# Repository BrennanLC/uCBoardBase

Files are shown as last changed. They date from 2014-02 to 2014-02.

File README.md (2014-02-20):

uCBoardBase
===========

Microcontroller breakout board built with the Texas Instruments TM4C123BE6PM.

Design has not yet been verified. Build at your own risk!

Files:

uCBoardBase.pdf - Copy of board schematic in PDF format
uCBoardBase.sch - Board schematic eagle file 
uCBoardBase.brd - Board layout eagle file
uCBoardBaseBoard.pdf - Board layout in PDF format

schematic and board layout built with Eagle 6.4.0 Standard. More info and 
download available here:

https://www.cadsoftusa.com/

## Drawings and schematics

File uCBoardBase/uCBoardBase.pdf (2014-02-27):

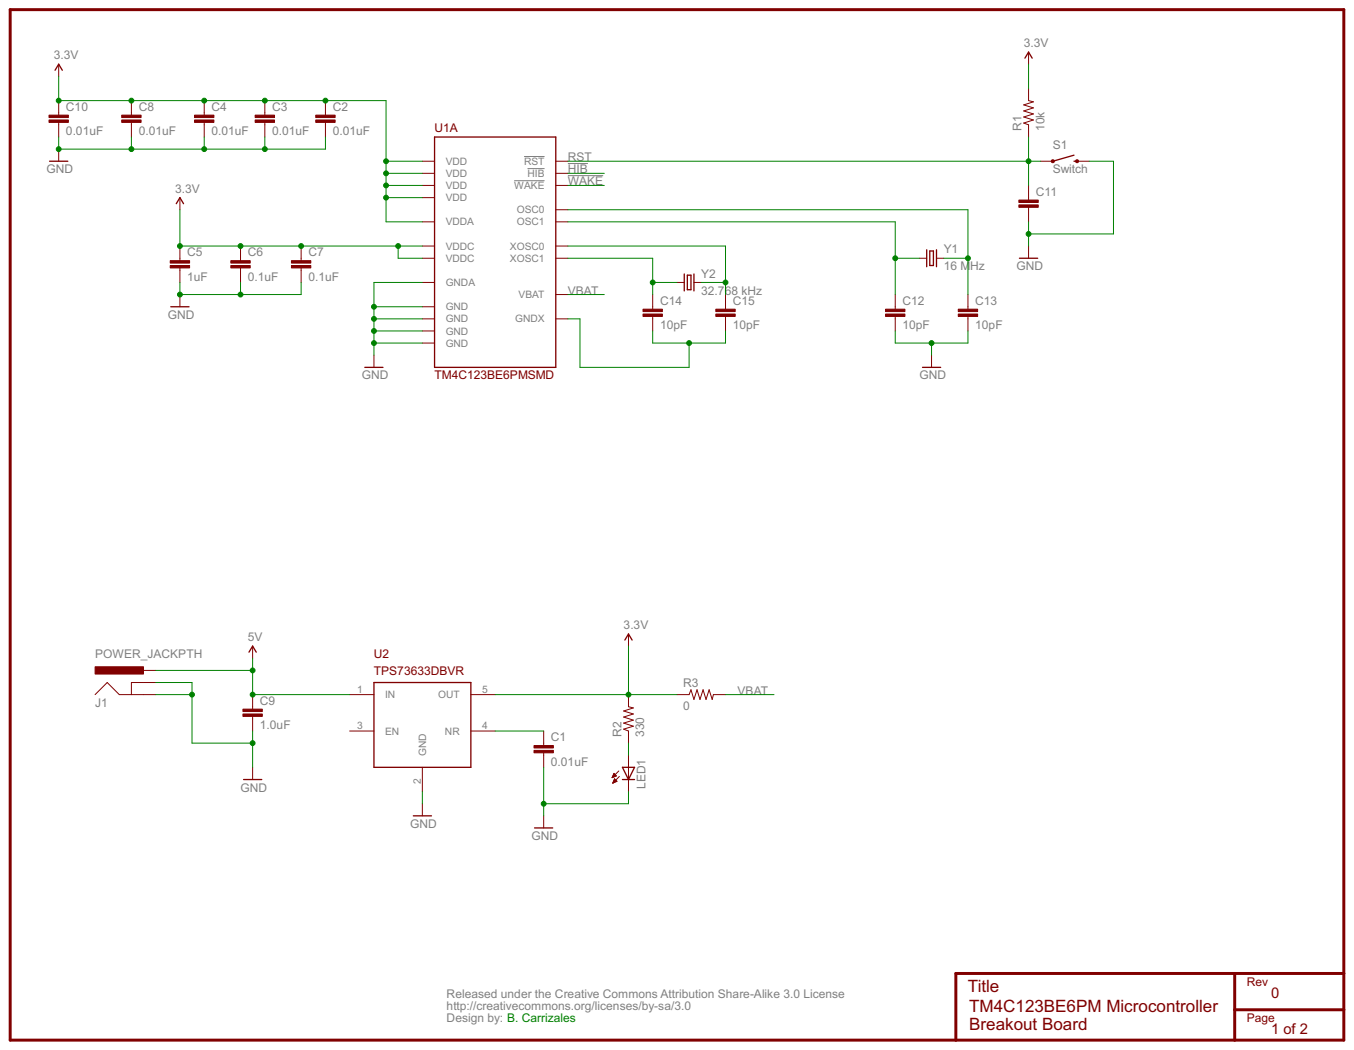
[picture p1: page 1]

VDDA
VDDC GNDA GND GND GND GND

Released under the Creative Commons Attribution Share-Alike 3.0 License
http://creativecommons.org/licenses/by-sa/3.0
Design by:

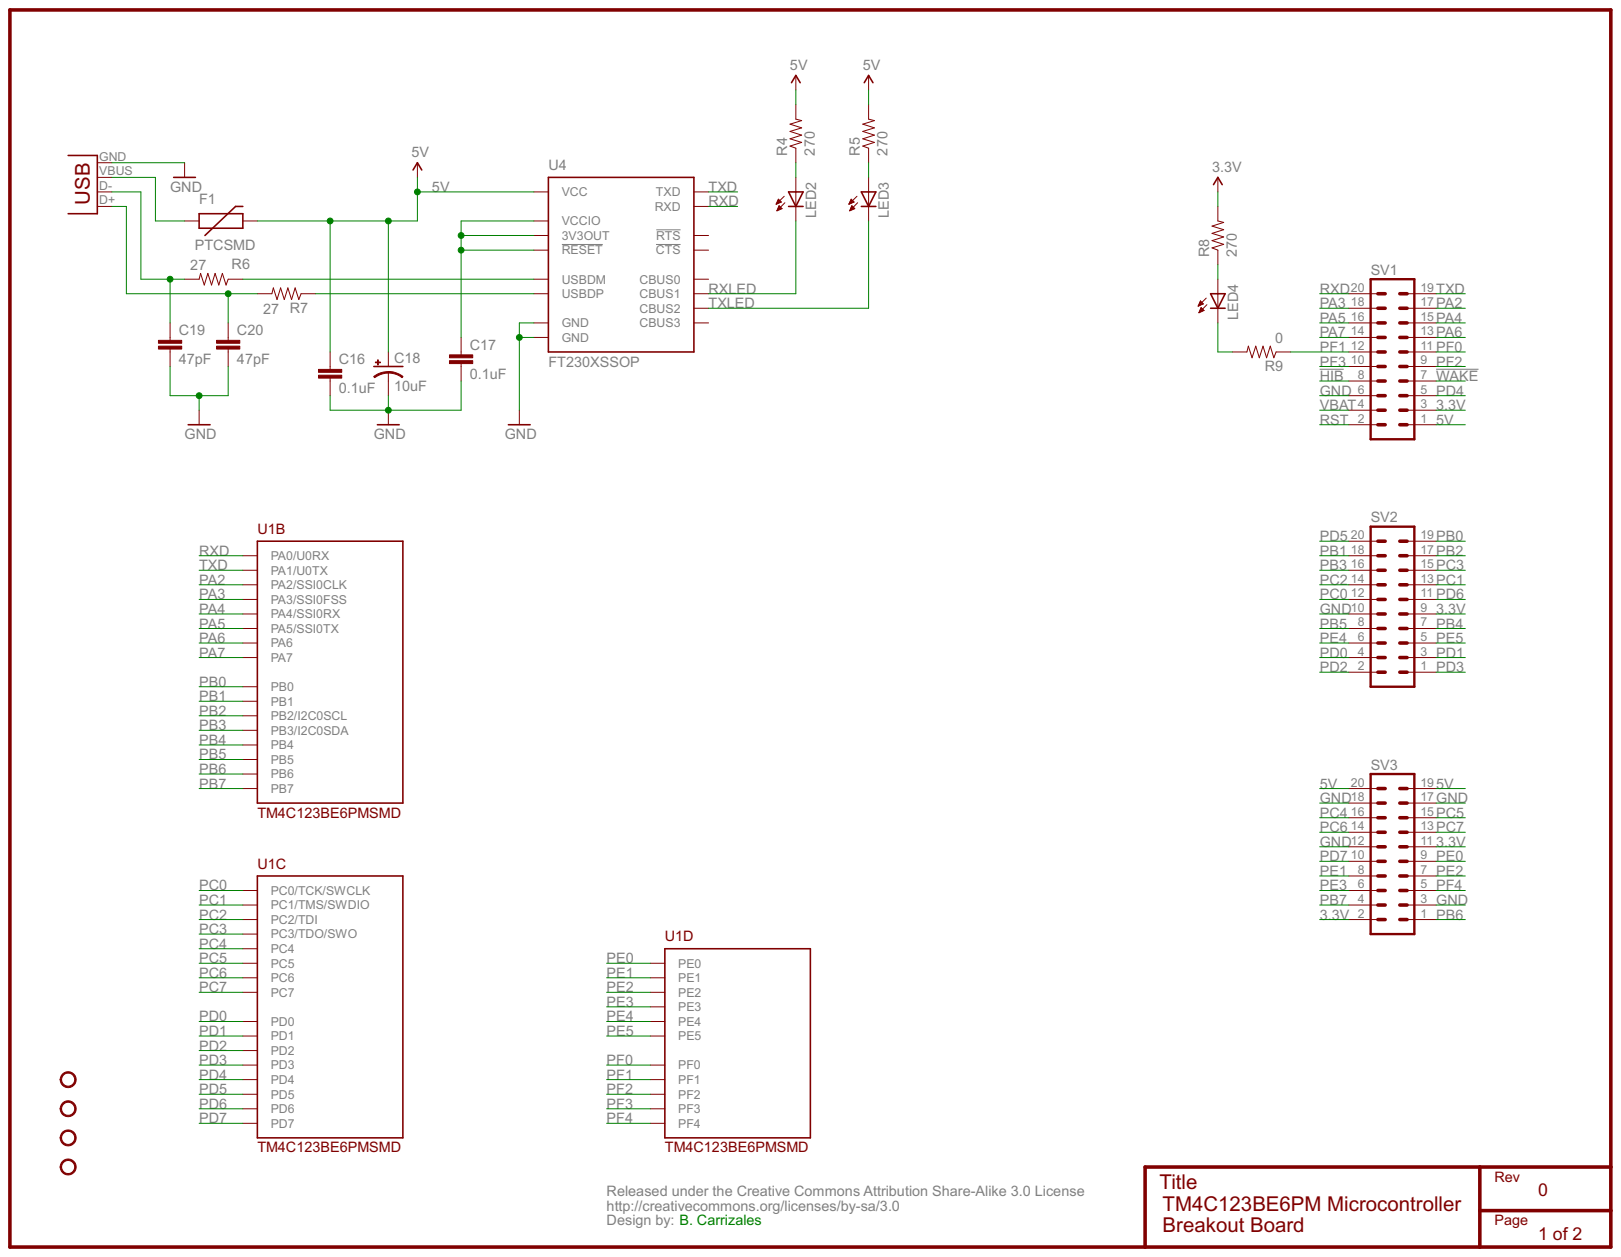
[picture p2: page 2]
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

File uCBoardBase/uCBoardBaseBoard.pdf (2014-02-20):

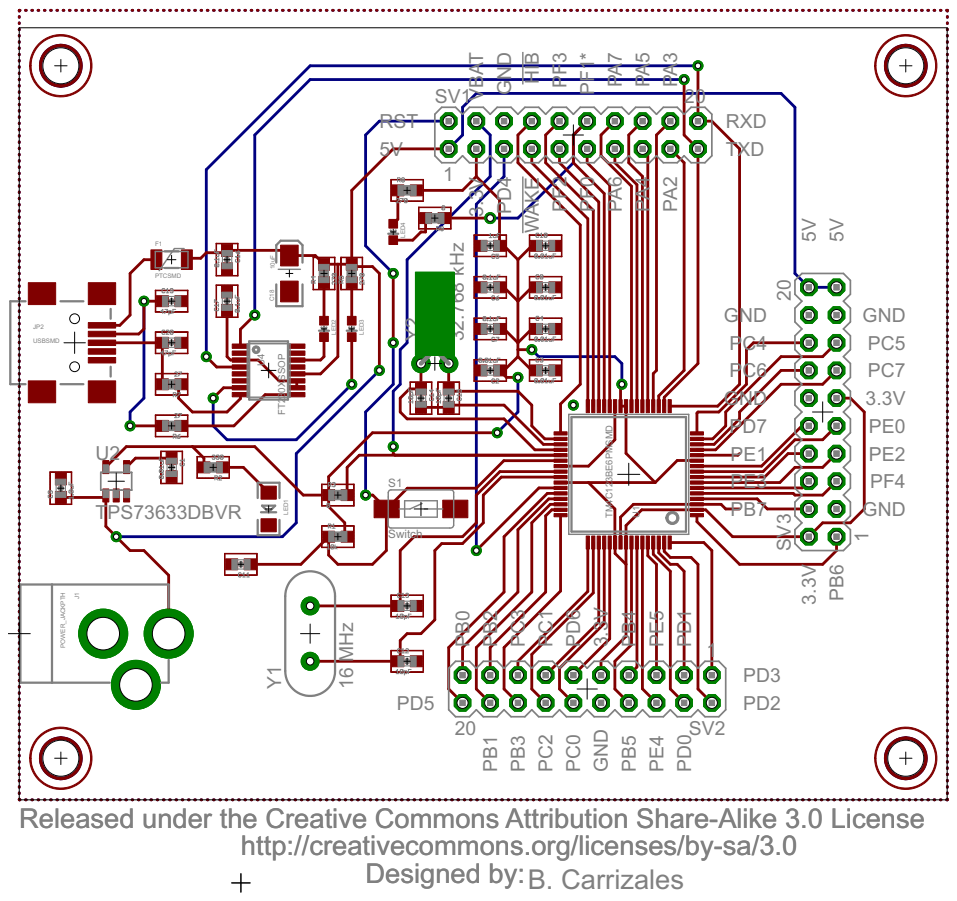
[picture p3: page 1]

POWER_JACKPTH Released under the Creative Commons Attribution Share-Alike 3.0 License

Released under the Creative Commons Attribution Share-Alike 3.0 License

http://creativecommons.org/licenses/by-sa/3.0

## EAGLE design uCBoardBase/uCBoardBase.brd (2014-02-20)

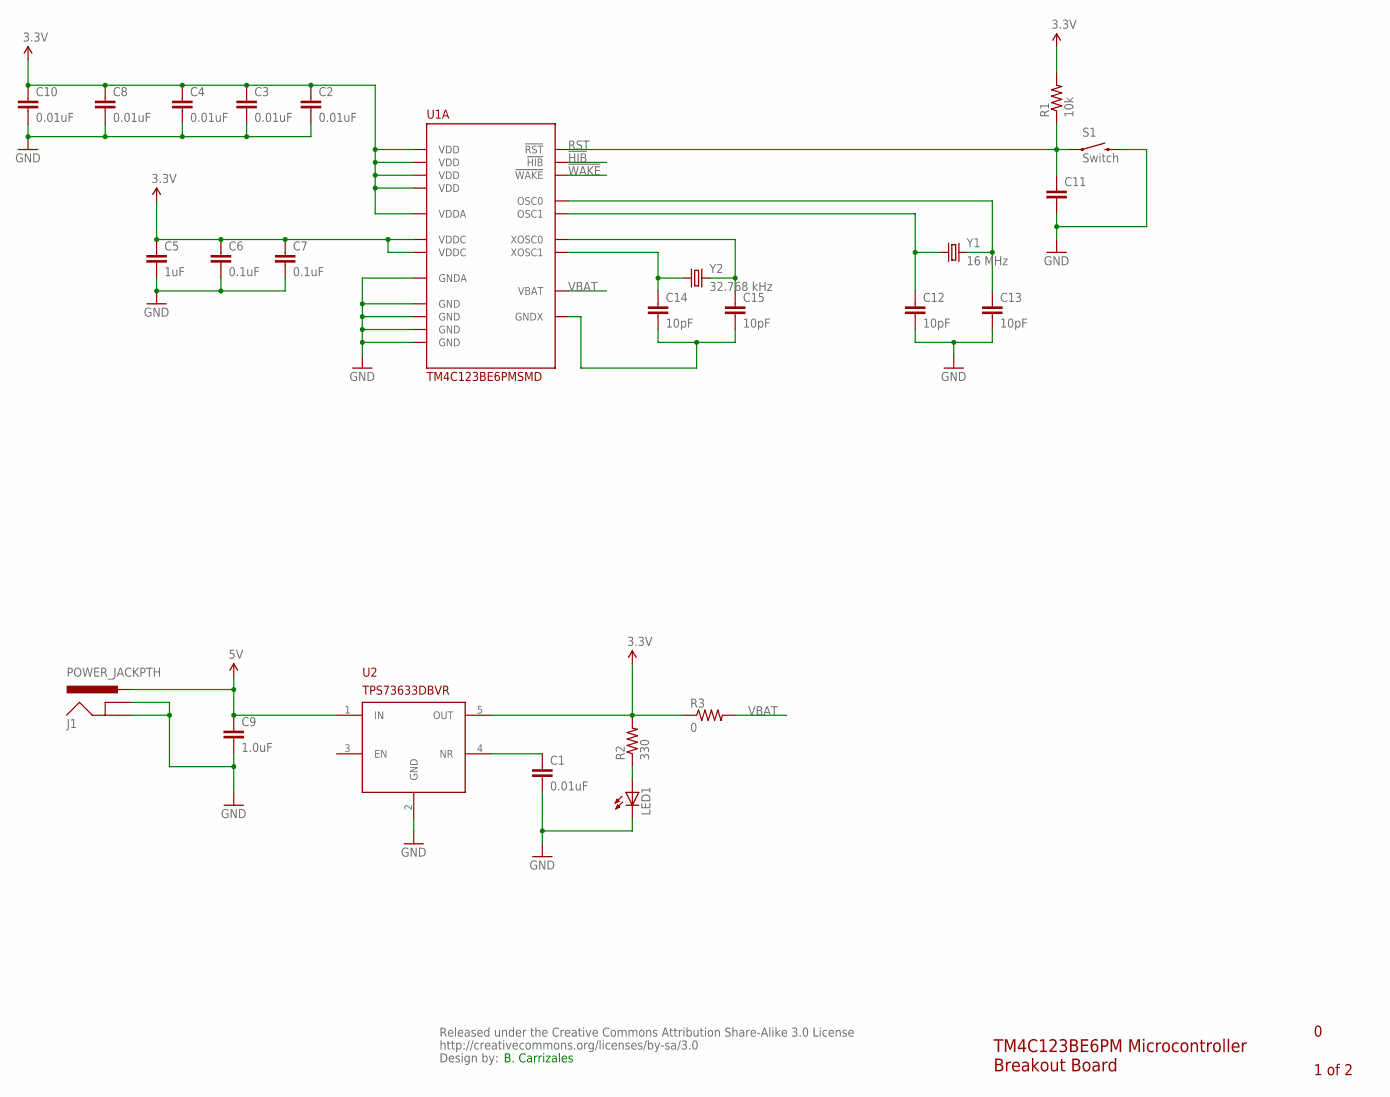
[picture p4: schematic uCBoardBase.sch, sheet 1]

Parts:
C1, C2, C3, C4, C8, C10: 0.01uF; 0603-CAP
C5: 1uF; 0603-CAP
C6, C7: 0.1uF; 0603-CAP
C9: 1.0uF; 0603-CAP
C11: CAP0603-CAP; 0603-CAP
C12, C13, C14, C15: 10pF; 0603-CAP
CC_TEXT1: CREATIVE_COMMONS
J1: POWER_JACKPTH; POWER_JACK_PTH
LED1: LED1206; LED-1206
R1: 10k; 0603-RES
R2: 330; 0603-RES
R3: 0; 0603-RES
S1: Switch; TACTILE-SWITCH-1101NE
U1: TM4C123BE6PMSMD; 64LQFP
U2: TPS73633DBVR; SOT23-DBV
Y1: 16 MHz; HC49US
Y2: 32.768 kHz; TC26H

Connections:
3.3V: C2.1, C3.1, C4.1, C5.1, C6.1, C7.1, C8.1, C10.1, R1.2, R2.2, R3.1, U1.2 (VDDA), U1.11 (VDD), U1.25 (VDDC), U1.26 (VDD), U1.42 (VDD), U1.54 (VDD), U1.56 (VDDC), U2.5 (OUT); also elsewhere on the board
5V: C9.1, J1.PWR, U2.1 (IN); also elsewhere on the board
!HIB: U1.33 (!HIB); also elsewhere on the board
!WAKE: U1.32 (!WAKE); also elsewhere on the board
GND: C1.2, C2.2, C3.2, C4.2, C5.2, C6.2, C7.2, C8.2, C9.2, C10.2, C11.2, C12.2, C13.2, J1.GND, J1.GNDBREAK, LED1.C, S1.P$2 (2), U1.3 (GNDA), U1.12 (GND), U1.27 (GND), U1.39 (GND), U1.55 (GND), U2.2 (GND); also elsewhere on the board
unnamed: C13.1, U1.40 (OSC0), Y1.2
unnamed: C12.1, U1.41 (OSC1), Y1.1
unnamed: C1.1, U2.4 (NR)
unnamed: LED1.A, R2.1
unnamed: C14.1, U1.36 (XOSC1), Y2.1
unnamed: C15.1, U1.34 (XOSC0), Y2.2
unnamed: C14.2, C15.2, U1.35 (GNDX)
RST: C11.1, R1.1, S1.P$1 (1), U1.38 (!RST); also elsewhere on the board
VBAT: R3.2, U1.37 (VBAT); also elsewhere on the board

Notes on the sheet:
TM4C123BE6PM Microcontroller Breakout Board
1 of 2
B. Carrizales

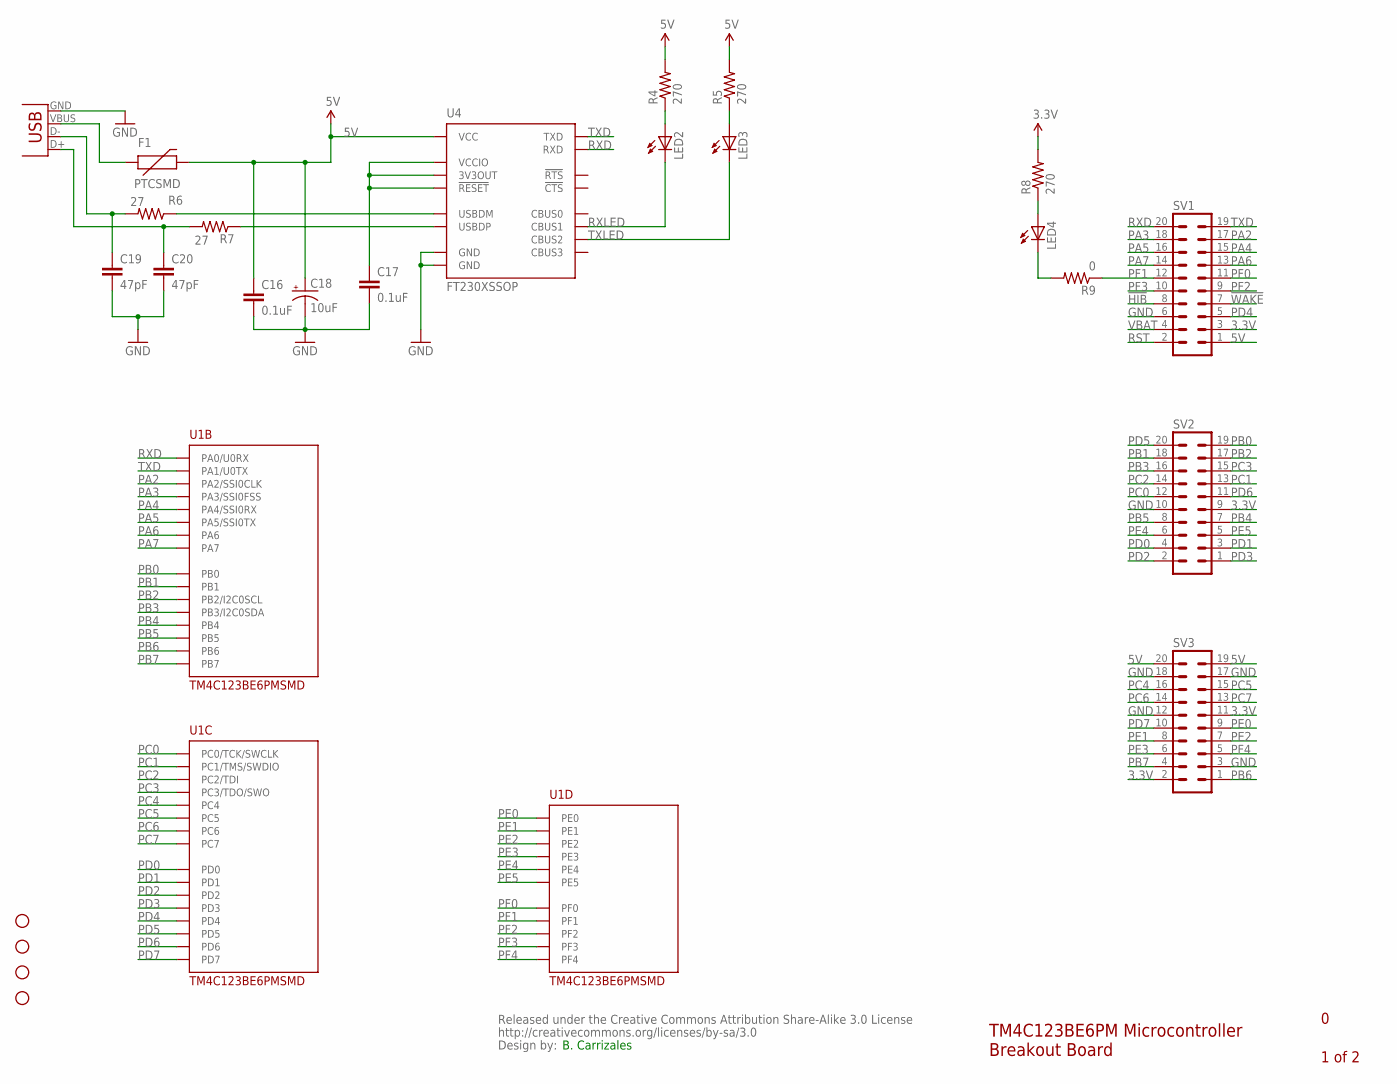
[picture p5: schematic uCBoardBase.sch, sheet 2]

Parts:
C16, C17: 0.1uF; 0603-CAP
C18: 10uF; EIA3216-KIT
C19, C20: 47pF; 0603-CAP
CC_TEXT2: CREATIVE_COMMONS
F1: PTCSMD; PTC-1206
JP2: USBSMD; USB-MINIB
LED2, LED3, LED4: LED0603; LED-0603
R4, R5, R8: 270; 0603-RES
R6, R7: 27; 0603-RES
R9: 0; 0603-RES
STANDOFF1, STANDOFF2, STANDOFF3, STANDOFF4: STAND-OFF
SV1, SV2, SV3: MA10-2
U1: TM4C123BE6PMSMD; 64LQFP
U4: FT230XSSOP; SSOP16

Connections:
3.3V: R8.2, SV1.3, SV2.9, SV3.2, SV3.11; also elsewhere on the board
5V: C16.1, C18.A (+), F1.2, R4.2, R5.2, SV1.1, SV3.19, SV3.20, U4.12 (VCC); also elsewhere on the board
!HIB: SV1.8; also elsewhere on the board
!WAKE: SV1.7; also elsewhere on the board
GND: C16.2, C17.2, C18.C (-), C19.2, C20.2, JP2.GND, SV1.6, SV2.10, SV3.3, SV3.12, SV3.17, SV3.18, U4.5 (GND), U4.13 (GND); also elsewhere on the board
unnamed: LED4.A, R8.1
unnamed: C19.1, JP2.D-, R6.2
unnamed: C20.1, JP2.D+, R7.2
unnamed: LED3.A, R5.1
unnamed: LED2.A, R4.1
unnamed: F1.1, JP2.VBUS
unnamed: R7.1, U4.8 (USBDP)
unnamed: R6.1, U4.9 (USBDM)
unnamed: C17.1, U4.3 (VCCIO), U4.10 (3V3OUT), U4.11 (!RESET)
PA2: SV1.17, U1.19 (PA2/SSI0CLK)
PA3: SV1.18, U1.20 (PA3/SSI0FSS)
PA4: SV1.15, U1.21 (PA4/SSI0RX)
PA5: SV1.16, U1.22 (PA5/SSI0TX)
PA6: SV1.13, U1.23 (PA6)
PA7: SV1.14, U1.24 (PA7)
PB0: SV2.19, U1.45 (PB0)
PB1: SV2.18, U1.46 (PB1)
PB2: SV2.17, U1.47 (PB2/I2C0SCL)
PB3: SV2.16, U1.48 (PB3/I2C0SDA)
PB4: SV2.7, U1.58 (PB4)
PB5: SV2.8, U1.57 (PB5)
PB6: SV3.1, U1.1 (PB6)
PB7: SV3.4, U1.4 (PB7)
PC0: SV2.12, U1.52 (PC0/TCK/SWCLK)
PC1: SV2.13, U1.51 (PC1/TMS/SWDIO)
PC2: SV2.14, U1.50 (PC2/TDI)
PC3: SV2.15, U1.49 (PC3/TDO/SWO)
PC4: SV3.16, U1.16 (PC4)
PC5: SV3.15, U1.15 (PC5)
PC6: SV3.14, U1.14 (PC6)
PC7: SV3.13, U1.13 (PC7)
PD0: SV2.4, U1.61 (PD0)
PD1: SV2.3, U1.62 (PD1)
PD2: SV2.2, U1.63 (PD2)
PD3: SV2.1, U1.64 (PD3)
PD4: SV1.5, U1.43 (PD4)
PD5: SV2.20, U1.44 (PD5)
PD6: SV2.11, U1.53 (PD6)
PD7: SV3.10, U1.10 (PD7)
PE0: SV3.9, U1.9 (PE0)
PE1: SV3.8, U1.8 (PE1)
PE2: SV3.7, U1.7 (PE2)
PE3: SV3.6, U1.6 (PE3)
PE4: SV2.6, U1.59 (PE4)
PE5: SV2.5, U1.60 (PE5)
PF0: SV1.11, U1.28 (PF0)
PF1: R9.1, SV1.12, U1.29 (PF1)
PF2: SV1.9, U1.30 (PF2)
PF3: SV1.10, U1.31 (PF3)
PF4: SV3.5, U1.5 (PF4)
RST: SV1.2; also elsewhere on the board
RXD: SV1.20, U1.17 (PA0/U0RX), U4.4 (RXD)
RXLED: LED2.C, U4.14 (CBUS1)
TXD: SV1.19, U1.18 (PA1/U0TX), U4.1 (TXD)
TXLED: LED3.C, U4.7 (CBUS2)
TXLED1: LED4.C, R9.2
VBAT: SV1.4; also elsewhere on the board

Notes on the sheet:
1 of 2
TM4C123BE6PM Microcontroller Breakout Board
B. Carrizales

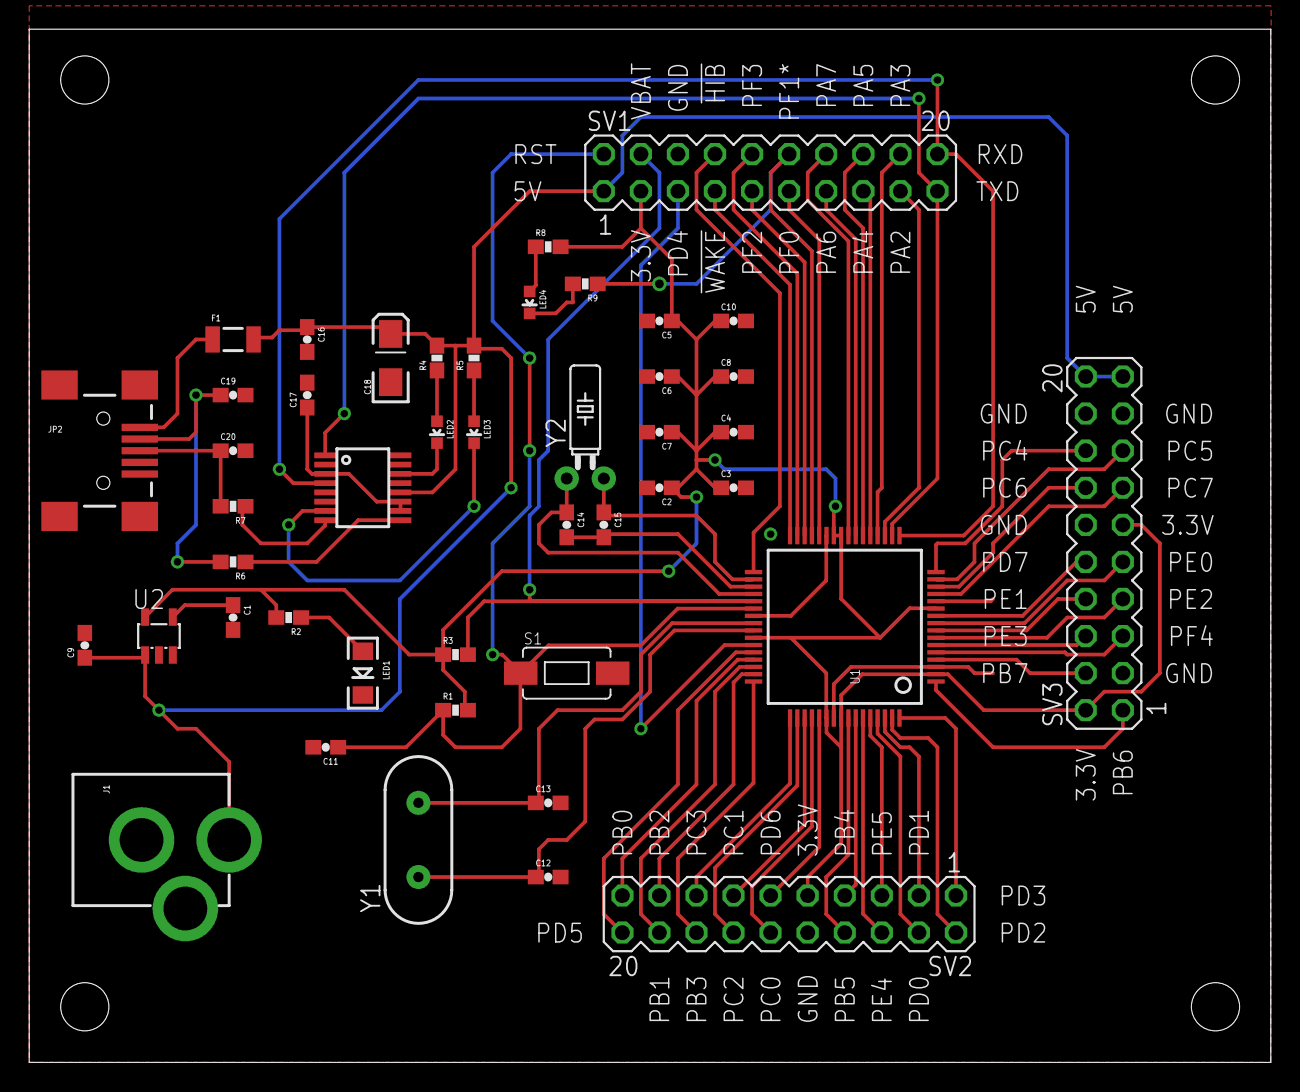
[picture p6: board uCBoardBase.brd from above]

Board: 2 copper layers, 85.1 x 70.8 mm, 51 parts (0 on the bottom side), 69 nets.

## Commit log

2013-11-08 Added Schematic
    Added schematic of uCBoardBase
    [uCBoardBase.sch]
2013-11-11 Updated Schematic
    Updated schematic
    [uCBoardBase.sch]
2013-11-28 Updated Schematic and Layout
    Updated schematic and finished board layout
    [uCBoardBase.brd, uCBoardBase.sch]

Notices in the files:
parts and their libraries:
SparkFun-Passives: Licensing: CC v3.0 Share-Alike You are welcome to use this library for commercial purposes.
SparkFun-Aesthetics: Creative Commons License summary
